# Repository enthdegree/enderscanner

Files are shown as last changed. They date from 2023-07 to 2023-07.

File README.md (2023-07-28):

# Ender Scan
### Tools for scanning film negatives with an Ender 3 Neo

An Ender 3 can be used as a film scanner:

 - Its large print volume fits a light panel and film carrier. 
 - A Raspberry Pi HD camera can be mounted face-down on the printhead and swept around to image segments of the film negative.
 - Those captures can be stitched.

A 6x6 frame scanned by this method. (using a kind of goofy inversion profile).
*A 6x6 frame scanned by this method. (using a kind of goofy inversion profile).*

## Why

> What is the motivation for doing this?

At the time of writing, most quality film scanning equipment is some combination of proprietary, aging, thousands of dollars and awkward to use and set up. 
It is possible the 3D printer approach can be refined into a viable alternative.

My motivation: because you can. :)

## Components

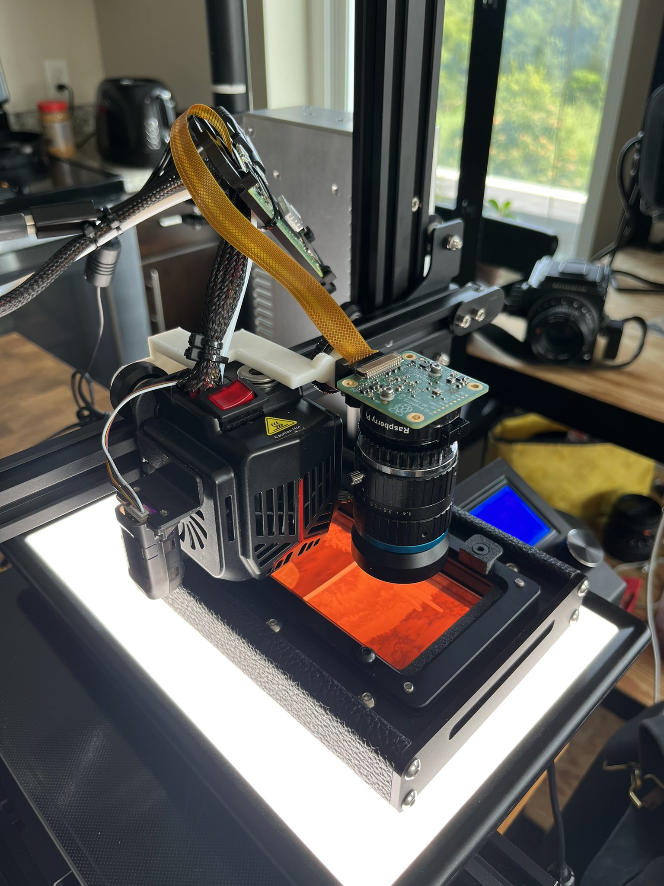
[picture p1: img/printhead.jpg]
Ender Scan print head over a backlit film negative.

*Ender Scan print head over a backlit film negative.*

In slightly more detail, the following pieces are involved (roughly in order of build and usage steps):
 
 - [`ender3_picamera_v2.scad`](./ender3_picamera_v2.scad): A bracket to mount the Raspberry Pi HD camera onto the print head with a couple M5 nuts and a camera screw like [this one](//www.amazon.com/dp/B0823HGR94). 
	- To reduce vibration, the Ender 3's printhead also needs to be modded with a switch to turn the front fan off. 
	Don't ever turn the fan off or leave the camera mounted during a print!
 - For development I am using the 16 mm C-mount lens with the RPi HD camera mount's back-focus adapter as a macro extension tube. 
 - A Raspberry Pi Zero W operates the camera via SSH, and the Ender 3 printhead via OctoPrint. 
	A separate 'host computer' is going to operate the camera and Ender 3 through this Zero W:
	- The Zero W has SSH access with no-password pubkey authentication. The host uses this interface to capture images & download them.
	- OctoPrint has a web interface with a REST API key for the main OctoPrint user. The host uses this interface to control the print head.
 - A bunch of scripts to run on the host computer that perform scan functions:
	- [`zup.py`](./zup.py): Draw the print head up to a "center" location + some Z displacement.
		After running this, roughly center the light panel + film negative underneath the camera. 
	- [`zstack.py`](./zstack.py): Capture a bunch of images of the film negative for a range of Z displacements, and download them to a folder on the host computer. 
		This is used to find the focus plane. 
	- [`basic_scan.py`](./basic_scan.py): Sweep the print head around to capture an X-Y grid of images, and download them to a folder on the host computer.
	- [`stitch.py`](./stitch.py): Attempts to stitch segments from `basic_scan.py` using panotools. The approach:
		1. Get control points for each group of 2x2 in the grid. 
		2. Make a new project file with all the control points, and find optimal positions.
		3. Produce a stitched .TIF with a blend tool. [multiblend](https://horman.net/multiblend/) works much faster here than Panotools' enblend.
  		4. If this fails it leaves project files for manual adjustment in a subdirectory.

## Possible future work

A lot more development and experimentation is needed to make this scan approach useful for "normal" users.
The high-level scan process facing the user and robustness of the steps involved both need improvement.
A few ideas are worth exploring:

 - `stitch.py` should by default automatically read the grid of segments available in the scan folder.
 - Mounting bracket that facilitates adjusting the lens toward parallel film plane.
 - Auto-exposure and auto-focus-finding, possibly per-segment. 
	This could benefit highly warped negatives or a misaligned lens.
 - Stitch routine that fails gracefully: some batches of scan segments will be difficult to stitch. 
	The stitch routine should detect when it didn't find good control points a 2x2 sub-problem, then hand the user an interface to position that part of the image visually, by hand.
 - Achieve higher effective color bit-depth by capturing multiple exposures and high-precision averaging. 
 - GUI wizard 
 - Automatic film advancement 
 - Nicer lens and sensor...

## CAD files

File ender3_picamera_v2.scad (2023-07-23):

// Mount a downward-facing Raspberry Pi HD camera on an Ender 3 print head
$fa = 1; 
$fs = 0.1;

// Dimensions
dilate = 1; // How much should hole diameters be expanded?

faceplate_bolt_diam = 5; // The mounting bolts are M5
faceplate_nut_diam = 8/cos(30);
faceplate_sep = 37.5; // Separation between the centers of the two wheels that roll along the X axis 
faceplate_nut_countersink = 3;
faceplate_extra_thickness = 1; // How thick should material be past the mount bolt countersink? (n.b. we only have 3mm of exposed mounting bolt thread to work with)
faceplate_shoulder = 3;
faceplate_total_depth = 2*faceplate_shoulder + 9;
faceplate_total_height = faceplate_extra_thickness + faceplate_nut_countersink;

printhead_back_height = 23; // Back of the print head's distance from zero
printhead_top_depth = 11.5; // (real-life-)z displacement to get from 0 to the top of the print head

camera_bolt_diam = 6.35; // The camera screw is a 1/4"-20
camera_bolt_height = 68; // How far (real-life-)forward from zero should the camera mount beam go?
camera_bolt_offset = 36; // How far to the (real-life-)right from zero is the camera bolt?
camera_bolt_depth = 11; // (real-life-)z displacement to get from 0 to the camera bolt center

// Faceplate definition
module faceplate_body() {
    translate([-dilate/2, -faceplate_total_depth/2, -faceplate_total_height/2]) {
         cube([(faceplate_sep+dilate)/2, faceplate_total_depth, faceplate_total_height]);
    }
    translate([faceplate_sep/2,0,-faceplate_total_height/2]) {
        cylinder(h=faceplate_total_height, d=faceplate_total_depth);
    }
};

module faceplate_holes() {
    // Mounting bolt screw hole
    translate([faceplate_sep/2, 0, 0]) {
        cylinder(h=faceplate_total_height+dilate, d=faceplate_bolt_diam+dilate,
        center=true);
    }

    // Mounting bolt countersink
    translate([faceplate_sep/2, 0, (+faceplate_total_height-faceplate_nut_countersink+dilate)/2]) {
        cylinder(h=faceplate_nut_countersink+dilate, 
            d1=faceplate_nut_diam,
            d2=faceplate_nut_diam+2*dilate,
            center=true);
    }
};

module half_faceplate_body() {
    difference() { 
        faceplate_body(); 
        faceplate_holes();
    }
};

module mount() {
    union() {
        half_faceplate_body();
        mirror([1,0,0]) half_faceplate_body();
    }
};

beam_width = faceplate_total_depth;
beam_thickness = faceplate_total_height;
camera_bolt_pt = [camera_bolt_offset, camera_bolt_depth, camera_bolt_height];

// Beam definition
module beam_body() {
    
    /*
    translate([0, camera_bolt_depth, camera_bolt_height/2]) cube(2,center=true);
    translate([0, camera_bolt_depth, camera_bolt_height/1]) cube(2,center=true);
    translate([camera_bolt_offset, camera_bolt_depth, camera_bolt_height/2]) cube(2,center=true);
    translate([camera_bolt_offset, camera_bolt_depth, camera_bolt_height/1]) cube(2,center=true);
    */
    
    // Beam from zero to top of printhead (depth extension)
    beam_0_ext = [0,printhead_top_depth,0];
    beam_0_overshoot = [0,beam_thickness,0];
    beam_0_dims = [beam_width, 0, beam_thickness] + beam_0_ext + beam_0_overshoot; 
    beam_0_c = (beam_0_ext+beam_0_overshoot)/2;
    translate(beam_0_c) cube(beam_0_dims, center=true);
    
    // From beam 0 to past print head coasters (height extension)
    beam_1_ext = [0,0,camera_bolt_height/2-beam_width];
    beam_1_overshoot = [0,0,beam_width];
    beam_1_dims = [beam_width, beam_thickness, 0] + beam_1_ext + beam_1_overshoot;
    beam_1_c = beam_0_c + beam_0_ext/2 + (beam_1_ext+beam_1_overshoot)/2;
    translate(beam_1_c) cube(beam_1_dims, center=true);

    // From beam 1 to right edge of print head (width extension)
    beam_2_ext = [camera_bolt_offset/4,0,0];
    beam_2_overshoot = [beam_width,0,0];
    beam_2_dims = [0, beam_thickness, beam_width] + beam_2_ext + beam_2_overshoot;
    beam_2_c = beam_1_c + beam_1_ext/2 + (beam_2_ext+beam_2_overshoot)/2;
    translate(beam_2_c) cube(beam_2_dims, center=true);

    // From beam 2 to bolt front (height extension)
    beam_3_ext = [0,0,camera_bolt_height/2+beam_width/2-beam_thickness];
    beam_3_overshoot = [0,0,beam_thickness];
    beam_3_dims = [beam_width, beam_thickness, 0] + beam_3_ext + beam_3_overshoot;
    beam_3_c = beam_2_c + beam_2_ext/2 + (beam_3_ext+beam_3_overshoot)/2;
    translate(beam_3_c) cube(beam_3_dims, center=true);                    
    // From beam 3 to bolt front (width extension)
    beam_4_ext = [beam_width,0,0];
    beam_4_overshoot = [0,0,0]; 
    beam_4_dims = [0, beam_thickness, beam_thickness] + beam_4_ext + beam_4_overshoot;
    beam_4_c = beam_3_c + beam_3_ext/2 + (beam_4_ext+beam_4_overshoot)/2 + [beam_width/2-beam_thickness,0,0];
    translate(beam_4_c) cube(beam_4_dims, center=true);
    
    translate(camera_bolt_pt-[0,0,beam_thickness/2])
    cylinder(h=beam_thickness, r=camera_bolt_diam+2*faceplate_shoulder/2-dilate/2, center=true);
    
    translate(camera_bolt_pt-[11,-3,beam_thickness/2])
    cylinder(h=beam_thickness, r=5, center=true);
}

module camera_bolt_hole() {
    translate(camera_bolt_pt)
    cylinder(h=beam_width,
        d=camera_bolt_diam + dilate, 
        center=true); 
}

module beam() {
    difference() {
        beam_body();
        camera_bolt_hole();
    }
}

union() {
    mount();
    beam();
}
